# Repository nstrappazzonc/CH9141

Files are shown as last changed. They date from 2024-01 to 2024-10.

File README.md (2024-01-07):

# CH9141

Este es un IC que permite la comunicación Bluetooth a través de la comunicación serial de forma transparente. Lo impresionante de este chip es su simplicidad de conexión electrónica con apenas cuatro componentes y su simple configuración mediante comandos AT. Es diseñado y fabricado en china por [Jiangsu Heng Qin Ltd. (WCH)](http://www.wch-ic.com).

Existen diferentes formas de conectar el Bluetooth, en este repositorio nos centraremos en cómo se indica en el siguiente diagrama, para conocer más formas de conexión vea él [datasheet](https://github.com/nstrappazzonc/CH9141/blob/main/doc/CH9141DS1.PDF).



Podrá usar el IC para conectarse directamente a un PC o móvil, vea los siguientes [ejemplos](https://github.com/openwch/ch9141).

Puedes conseguir los IC o una placa de pruebas en la tienda oficial de [AliExpress](https://wchofficialstore.es.aliexpress.com/store/1100367542) o en [LCSC](https://www.lcsc.com).

De momento nos vamos a centrar en él [CH9141K](https://www.wch-ic.com/products/CH9141.html) que tiene unas prestaciones muy versátiles, entre ellas destacan las siguientes:

- Soporta el estándar Bluetooth BLE4.2 que es de bajo consumo.
- Llega hasta 100 metros de distancia.
- Soporta la configuración mediante comandos AT.
- Soporta diferentes modos: broadcast, host y slave.
- Permite una comunicación asíncrona de hasta 5Mbps.

## Componentes

Use los siguientes componentes para construir el circuito mínimo:

- Un IC CH9141K.
- Oscilador externo de 32MHz 10PPM y 12pF.
- Dos capacitores 2.2 uF.

## Proyectos relacionados

- [CH334 - HUB USB 2.0](https://github.com/nstrappazzonc/CH334)
- [CH340 - USB 2.0 to Serial](https://github.com/nstrappazzonc/CH340)
- [CH552 - 8-bits MCU - 8051](https://github.com/nstrappazzonc/CH552)

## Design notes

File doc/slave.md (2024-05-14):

7.3 Slave Mode
Step1. Set the basic parameters, baud rate, working mode, etc. The chip restarts, the UART will work according to the set parameters, and the relevant setting information parameters of the device mode can be set.
Step2. Enter the AT mode to query the connection status, or directly perform the transparent transmission. When not connected, the transmitted data will be directly discarded;
Step3. Use software or the host to connect to the chip for transparent data transmission. During the transparent transmission period, AT configuration will cause that data received by BLE is directly discarded.

baud rate
working mode
restart

# Working mode, 2 slave.
AT+BLEMODE?
AT+BLEMODE=2

# MAC Address
AT+CCADD?
AT+CCADD=05:DF:39:4C:99:B1
# Chip name
AT+NAME?
AT+NAME=nicola

# Device name
AT+PNAME?
AT+PNAME=nicola

# System ID
AT+SYSID?

# chip name of device info
AT+MODNAME?
AT+MODNAME=nicola

# Serial num
AT+SERINUM?

AT+MANUNAME?

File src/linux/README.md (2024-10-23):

# Example Source Code / Linux

En este directorio hay de momento un código fuente en C++ para Linux para hacer uso de la librería WCHBLElib que es proporcionada por el fabricante, es un `.so` (shared object). Con este código de ejemplo puede realizar la comunicación desde el PC al CH9141.

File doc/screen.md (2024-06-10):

# screen

sudo screen /dev/ttyUSB0 1152200

Para salir, `CTRL+a`, luego preciona la letra `k`, antes de cerrar la terminal nos pregunta si estamos de acuerdo con terminar la terminal, presionamos `y` para aceptar.

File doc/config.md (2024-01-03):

# Configuración

El IC debe ser configurado mediante comandos AT a través del protocolo UART, puede usar el IC [CH340](https://github.com/nstrappazzonc/CH340) para conectarse e interactuar. Recuerde que debe iniciar el IC en `AT mode`, para eso debe conectar el puerto AT a GND.

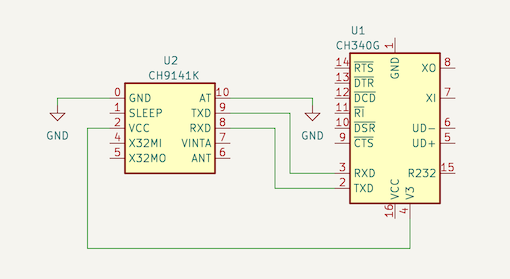
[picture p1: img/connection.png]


El diagrama anterior solo muestra la conexión entre un CH340G y CH9141K de forma orientativa para establecer la comunicación necesaria para la configuración y pruebas básicas.

Para practicar y entender mejor todo lo que se explica, haga uso de la [siguiente guía para crear un entorno de desarrollo](https://github.com/nstrappazzonc/CH9141/blob/main/doc/development.md).

## Clientes

Listamos una serie de clientes recomendados para conectarnos, luego la configuración que deberá definir para establecer la conexión:

- Linux: [moserial](https://wiki.gnome.org/Apps/Moserial), minicom, screen.
- MAC: [CoolTerm](https://freeware.the-meiers.org).
- Windows: [PuTTY](https://www.chiark.greenend.org.uk/~sgtatham/putty/latest.html).

**NOTA:** Tener cuidado que algunos clientes que no permiten enviar comandos como `tio`.

Para conectarnos, el IC utiliza las siguientes propiedades de conexión por defecto, las mismas que deberá definir en el cliente:

- Port: Depende del sistema operativo.
- Baudrate: 115200
- Data bits: 8
- Stop bits: 1
- Parity: none

## Lo básico

La sintaxis de los comandos AT que serán usadas es la siguiente:

```
<AT><+><COMMAND><operator><parameter><{CR}{LF}>
```

Todo comando empieza por `AT`, el símbolo `+` es opcional, más adelante hablaremos de los `COMMAND` más importantes, el `operator` hace referencia a dos modos; obtener `?` o definir `=`, luego tenemos el `parameter` que indica el nuevo valor que se le asignara y por último `<{CR}{LF}>` que hace referencia a `\r\n`. Es importante terminar cada comando con `<{CR}{LF}>` sino este no será ejecutado.

Si la instrucción es recibida por el host de forma satisfactoria, este responderá con un `<OK><{CR}{LF}>`. De lo contrario, responderá un mensaje de error `<{CR}{LF}><ERR:><error code><{CR}{LF}>`.

Cuando se conecta al IC con la configuración por defecto de fábrica, podrá recibir un mensaje que dice `Welcome` y si escribe `AT...` recibirá un `OK`. Este último comando es utilizado para verificar que la conexión es correcta.

Si queremos preguntar el nombre del dispositivo lo hacemos de la siguiente forma:

```
AT NAME?
```

Si queremos configurar un nuevo nombre al dispositivo, hágalo de la siguiente forma:

```
AT NAME=demo
AT SAVE
AT RESET
```

Para este caso estamos usando tres comandos, el primero `AT NAME=demo` le está asignando un nombre, el segundo `AT SAVE` guarda la configuración y el tercero `AT RESTART` reinicia el IC para que se inicie con los nuevos cambios.

## Errores

| Code | Mensaje |
|:----:|---|
|  01  | Error de cache, el chip no tiene cache para responder, debe intentar más tarde. |
|  02  | Error de parámetro, no está completo o bien formado la secuencia completa del comando AT. |
|  03  | Comando no soportado, puede que algún comando no esté soportado según el modo actual. |
|  04  | El comando no puede ser ejecutado, el comando no puede ser ejecutado temporalmente y deberá intentarlo luego. |

## Lista de comandos

Listamos los comandos necesarios para el CH9141K, para obtener más detalle no olvide consultar el [datasheet](https://github.com/nstrappazzonc/CH9141/blob/main/doc/CH9141DS1.PDF).

| Comando  | Descripción |
|---|---|
|AT... | Entra en el modo de configuración AT. |
|AT RESET  | Reinicia el chip, **no** borra la configuración. |
|AT VER | Obtiene el número de versión del chip. |
|AT HELLO  | Obtiene/Define el mensaje de bienvenida. |
|AT RELOAD | Reinicia todos los parámetros. |
|AT SAVE | Guarda todos los parámetros. |
|AT EXIT | Sale del modo de configuración AT. |
|AT UART | Obtiene/Define los parámetros del UART. |
|AT MAC | Obtiene la dirección local del MAC. |
|AT TPL | Obtiene/Define la potencia de transmición. |
|AT BLESTA | Obtiene el estado del Bluetooth. |
|AT DISCONN| Desconecta la actual conección. |
|AT BLEMODE| Obtiene/Define el modo del Bluetooth. |
|AT CCADD  | Obtiene la dirección MAC. |
|AT NAME | Obtiene/Define el nombre del chip, max 18 carácteres. |
|AT PNAME  | Obtiene/Define el nombre del dispositivo, max 18 carácteres.|

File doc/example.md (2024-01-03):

# Ejemplo de configuración

## Host

## Slave

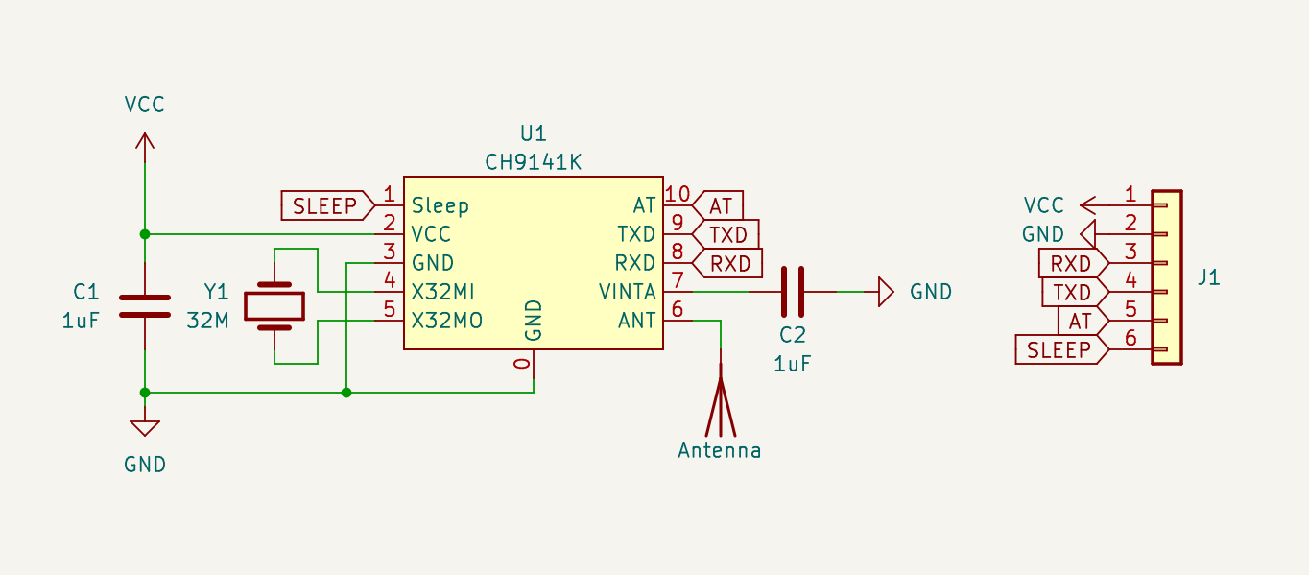
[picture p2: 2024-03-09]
img/minimal_schematic.png

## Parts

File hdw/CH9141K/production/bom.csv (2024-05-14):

Designator | Footprint | Quantity | Value | LCSC Part #
AE2 | Texas_SWRA117D_2.4GHz_Right | 1 | Antenna_Shield
C1, C2 | C1206 | 2 | 1uF
H1, H2, H3, H4 | MountingHole_3.2mm_M3 | 4 | MountingHole
J2 | PinHeader_1x03_P2.54mm_Vertical | 1 | Conn_01x03
J3 | PinHeader_1x04_P2.54mm_Vertical | 1 | Conn_01x04
U1 | ESSOP-10 | 1 | CH9141K
Y1 | Crystal_SMD_5032-2Pin_5.0x3.2mm_HandSoldering | 1 | 32M

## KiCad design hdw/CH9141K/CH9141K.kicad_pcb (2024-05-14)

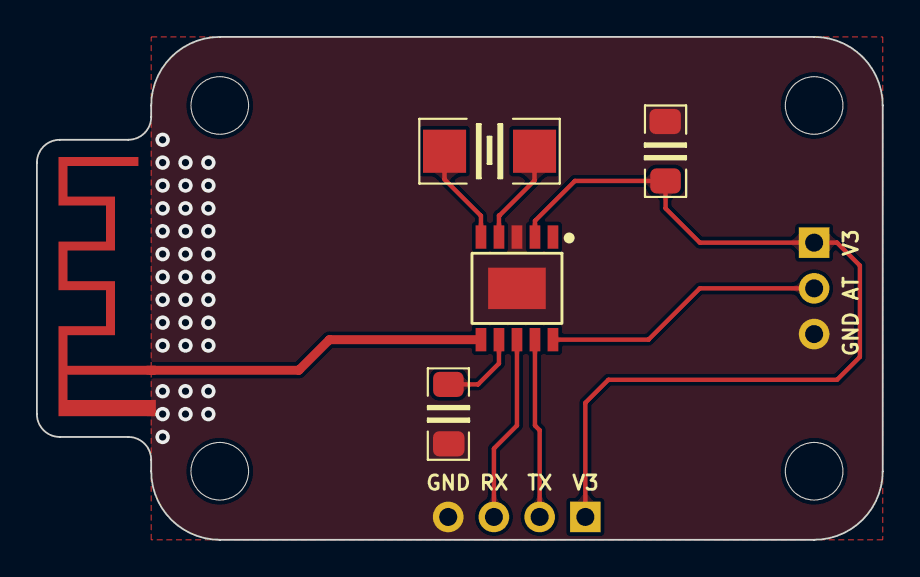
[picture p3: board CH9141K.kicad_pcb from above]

Board: 2 copper layers, 47.0 x 27.9 mm, 11 parts (0 on the bottom side), 9 nets.

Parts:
AE2: Antenna_Shield; Texas_SWRA117D_2.4GHz_Right
C1, C2: 1uF; C1206
H1, H2, H3, H4: MountingHole; MountingHole_3.2mm_M3
J2: Conn_01x03; PinHeader_1x03_P2.54mm_Vertical
J3: Conn_01x04; PinHeader_1x04_P2.54mm_Vertical
U1: CH9141K; ESSOP-10
Y1: 32M; Crystal_SMD_5032-2Pin_5.0x3.2mm_HandSoldering

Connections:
AT: J2.2, U1.10 (AT)
GND: C1.2, C2.2, J2.3, J3.4, U1.0 (GND), U1.3 (GND)
unnamed: AE2.1 (A), U1.6 (ANT)
unnamed: C2.1, U1.7 (VINTA)
unnamed: U1.4 (X32MI), Y1.2
unnamed: U1.5 (X32MO), Y1.1
RXD: J3.3, U1.8 (RXD)
TXD: J3.2, U1.9 (TXD)
VCC: C1.1, J2.1, J3.1, U1.2 (VCC)

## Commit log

2024-03-09 wip - schematic & pcb for CH9141K
    [CH9141K.kicad_pcb, CH9141K.kicad_sch, minimal.kicad_sch]
2024-03-10 poc - schematic & pcb for CH9141K
    [CH9141K.kicad_pcb, CH9141K.kicad_sch, bom.csv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]
2024-03-12 update pcb design
    [CH9141K.kicad_pcb]
